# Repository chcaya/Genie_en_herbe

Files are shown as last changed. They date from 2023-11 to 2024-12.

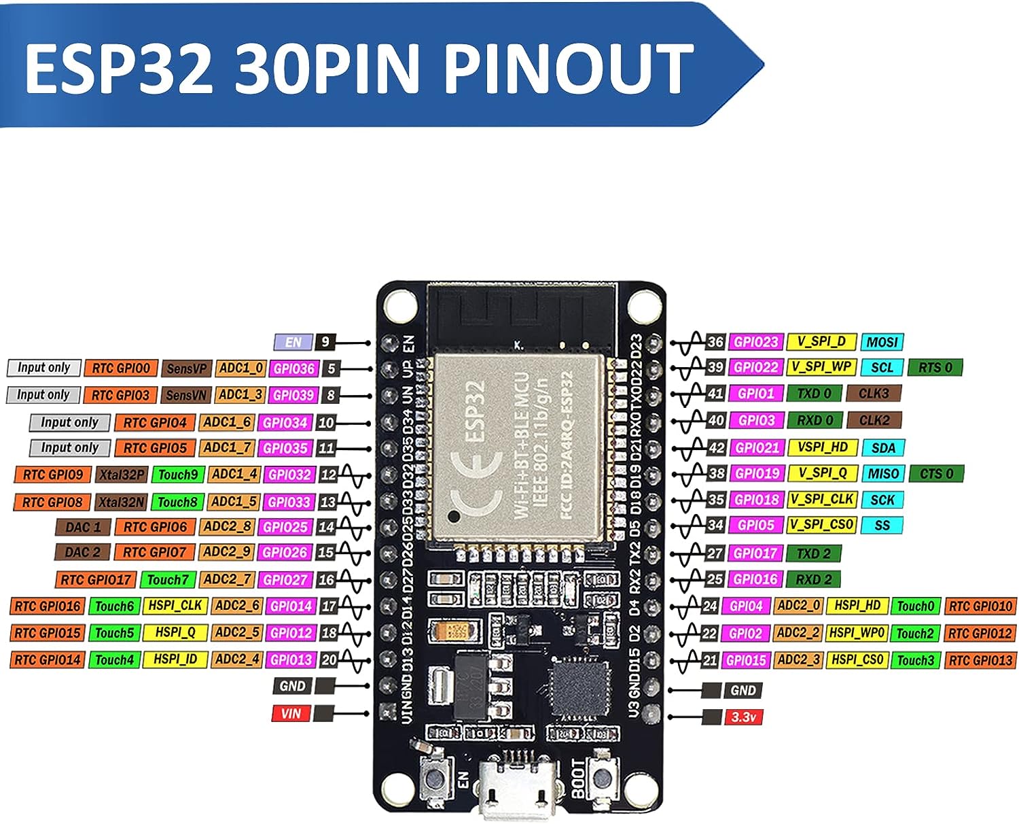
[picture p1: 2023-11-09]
MCU/DEV/ESP32/ESP32_PINOUT.jpg

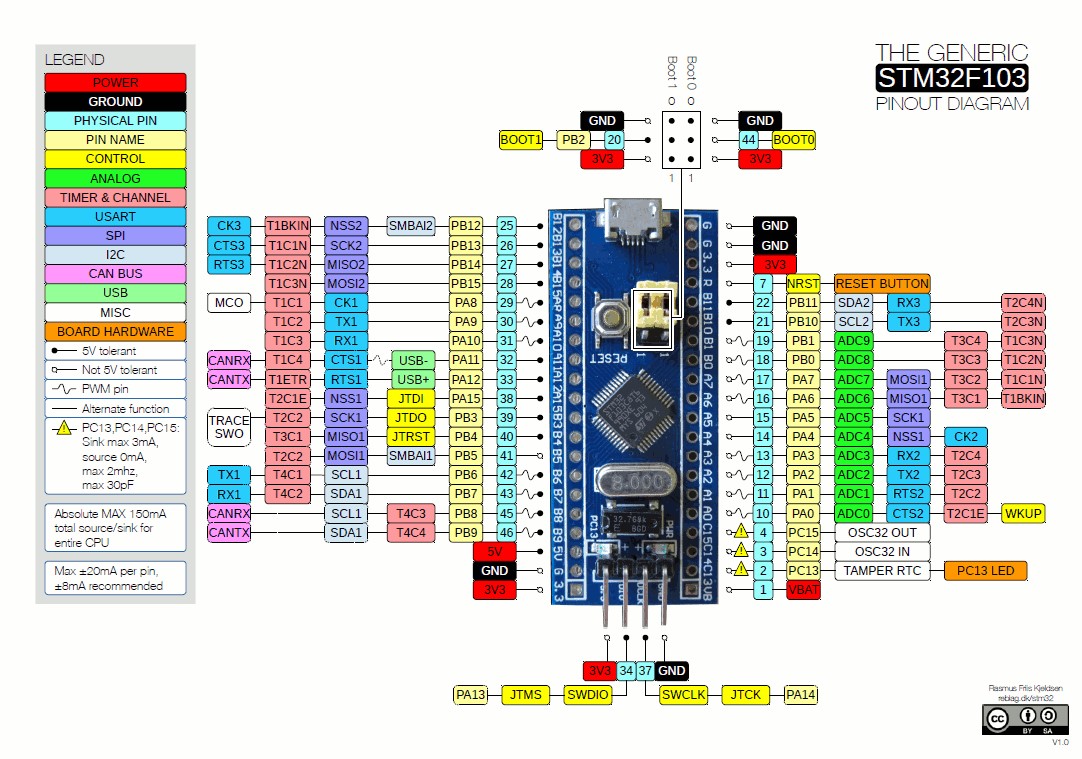
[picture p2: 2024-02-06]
MCU/DEV/STM32/STM32F103C8T6-Blue-Pill-Pin-Layout.jpg

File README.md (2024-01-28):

# Genie_en_herbe
Hardware, Firmware et Software pour la fabrication d'un jeu de génie en herbe

## Imprimer les fichiers STL dans le dossier /CAD/STL<br />
2x Handle_V4_Body_P1<br />
2x Handle_V4_Body_P2<br />
2x Handle_V4_Body_P3<br />
2x Handle_V4_Body_P4<br />
8x Handle_V4_Cover<br />
1x ESP32_CASE_V4_BASE<br />
1x ESP32_CASE_V4_COVER<br />

## Assemblage électrique
1- Connecter les grounds du ESP32 à 2 connecteurs Wago 5 pos<br />
2- Utiliser les connecteurs Wago 5 pos pour grounder tous les boutons (Fil noir)<br />
3- Connecter le fil rouge des boutons aux pins D15, D4, D16, D17 pour l'équipe 1<br />
4- Connecter le fil rouge des boutons aux pins D13, D14, D27, D26 pour l'équipe 2<br />
5- Passer les fils rouge et noir dans le trou de la poignée avant de souder les boutons sur ceux-ci<br />
6- Souder les fils rouge et noir sur les boutons<br />

## Assemblage mécanique
1- Utiliser 2x vis M3x16mm et 2x écrous pour assembler une poignée<br />
*Attention de faire sortir les fils par le trou central prévu à cet effet avant de visser solidement l'assemblage<br />
2- Utiliser 4x vis M3x16mm et 4x inserts pour assembler le boitier de jeu<br />
*Attention de faire sortir les fils par les 8 trous sur les côtés du boitier avant de visser solidement l'assemblage<br />

## Script code embarqué
1- Connecter l'ESP32 à l'ordinateur à l'aide du fil micro-USB (Valider la reconnaissance par l'ordinateur via le gestionnaire de périphériques)<br />
*Si celui-ci n'est pas reconnu, télécharger les drivers à partir de "/MCU/DEV/CP210x_Windows_Drivers_with_Serial_Enumeration/CP210xVCPInstaller_x86.exe"<br />
2- Lancer le script "MCU/UploadScript.exe" pour télécharger le code sur l'ESP32<br />
3- Attendre que tous les fichiers (bootloader.bin, partitions.bin et firmware.bin) soient correctement téléchargés avant d'interrompre le processus<br />

## Application GUI
1- Lancer l'application "/GUI/GEH_GUI.exe" lorsque l'ESP32 est connecté à l'ordinateur<br />
2- Sélectionner les équipes à l'aide des menus déroulants<br />
3- Lorsqu'un joueur appuie sur son bouton, le GUI indique le numéro et l'équipe du joueur<br />
4- Pour passer au prochain tour, il est possible d'appuyer sur le bouton "Reset" avec la souris ou simplement sur "Enter" avec le clavier

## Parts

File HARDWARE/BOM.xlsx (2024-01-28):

Qté d'unités | 1
Composant | Coût | Qté/unité | Qté lot | Coût/unité | Qté Amazon | Coût total | Lien
Boutons poussoirs* | 13.99 $ | 8 | 24 | 4.66 $ | 1 | 13.99 $ | https://www.amazon.ca/-/fr/gp/product/B07YCC4GTD/ref=ox_sc_act_title_8?smid=A86AD06S3OMVQ&psc=1
STM32* | 13.99 $ | 1 | 2 | 7.00 $ | 1 | 13.99 $ | https://www.amazon.ca/-/fr/gp/product/B0CKSYSSCZ/ref=ewc_pr_img_7?smid=A1ZMZWM9Z42FJB&psc=1
ESP32* | 22.16 $ | 0 | 2 | 0.00 $ | 0 | 0.00 $ | https://www.amazon.ca/-/fr/gp/product/B0BD4DVHZ9/ref=ox_sc_act_title_1?smid=A2K4DGCC72N9AG&psc=1
Fils micro USB 2m | 10.70 $ | 1 | 3 | 3.57 $ | 1 | 10.70 $ | https://www.amazon.ca/-/fr/gp/product/B08J3QCR8X/ref=ox_sc_act_title_6?smid=A2Y8CZ3LRW00G4&psc=1
Fils boutons (m) | 12.99 $ | 16 | 20 | 10.39 $ | 1 | 12.99 $ | https://www.amazon.ca/-/fr/gp/product/B074386X3V/ref=ox_sc_act_title_5?smid=A3UENWQOYWIPH9&psc=1
PLA | 31.99 $ | 0.3 | 1 | 9.60 $ | 1 | 31.99 $ | https://www.amazon.ca/-/fr/gp/product/B099KS2PDW/ref=ox_sc_act_title_1?smid=A3MZ696ES2UN1L&psc=1
Inserts | 10.59 $ | 4 | 100 | 0.42 $ | 1 | 10.59 $ | https://www.amazon.ca/-/fr/gp/product/B0BTYF2MMD/ref=ox_sc_act_title_4?smid=AKD305N0T0Z49&psc=1
Vis M3x16mm | 12.99 $ | 20 | 100 | 2.60 $ | 1 | 12.99 $ | https://www.amazon.ca/-/fr/t%C3%AAte-cylindrique-alliage-dacier-qualit%C3%A9/dp/B0BW891786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
Écrous M3 | 14.18 $ | 16 | 100 | 2.27 $ | 1 | 14.18 $ | https://www.amazon.ca/-/fr/%C3%A9crous-hexagonaux-auto-bloquants-inoxydable-ins%C3%A9r%C3%A9s/dp/B075ZZW7VL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
Borniers Wago 5 pos | 16.62 $ | 2 | 10 | 3.32 $ | 1 | 16.62 $ | https://www.amazon.ca/-/fr/gp/product/B06XH47DC2/ref=ewc_pr_img_8?smid=A3GIOIXY0M9FL0&psc=1
Connecteurs Dupont | 18.92 $ | 2 | 20 | 1.89 $ | 1 | 18.92 $ | https://www.amazon.ca/-/fr/gp/product/B07CTHCG5T/ref=ox_sc_act_title_2?smid=A3KY66I36TSYAT&psc=1
 |  |  |  | 45.72 $ |  | 156.96 $
*Même modèles nécessaires

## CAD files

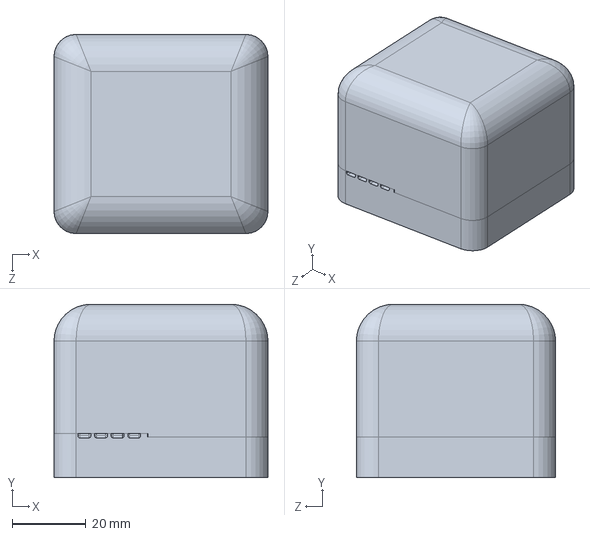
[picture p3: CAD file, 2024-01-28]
CAD/ESP32_CASE_V4.SLDPRT
58.0 x 47.0 x 54.0 mm

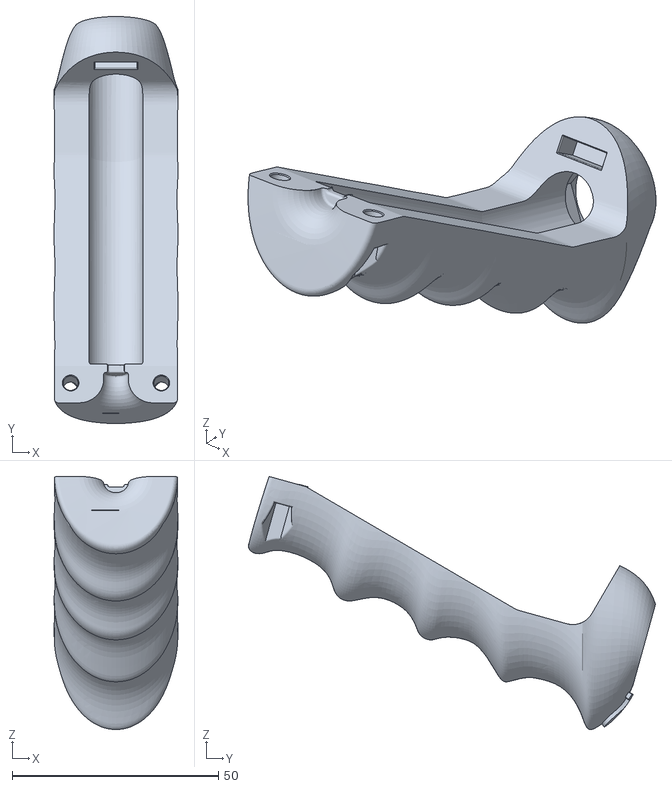
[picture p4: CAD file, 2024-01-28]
CAD/STL/Handle_V4_Body_P2.STL
30.0 x 98.6 x 61.4

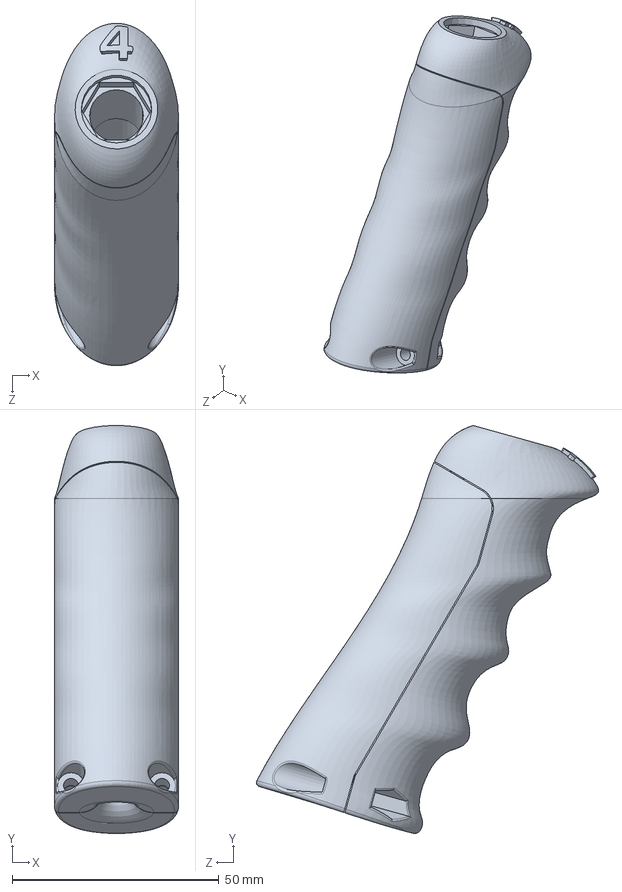
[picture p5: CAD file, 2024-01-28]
CAD/Handle_V4.SLDPRT
30.0 x 98.6 x 82.8 mm

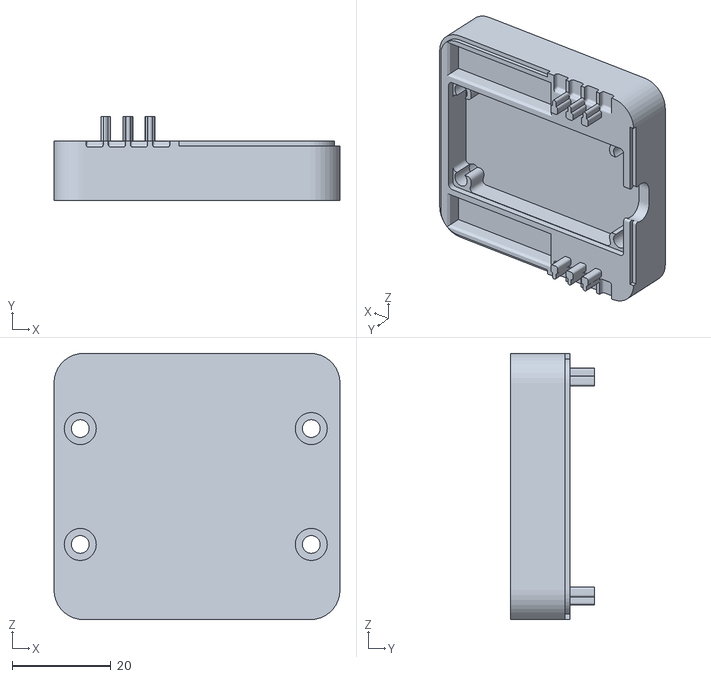
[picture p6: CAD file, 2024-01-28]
CAD/STL/ESP32_CASE_V4_BASE.STL
58.0 x 17.0 x 54.0

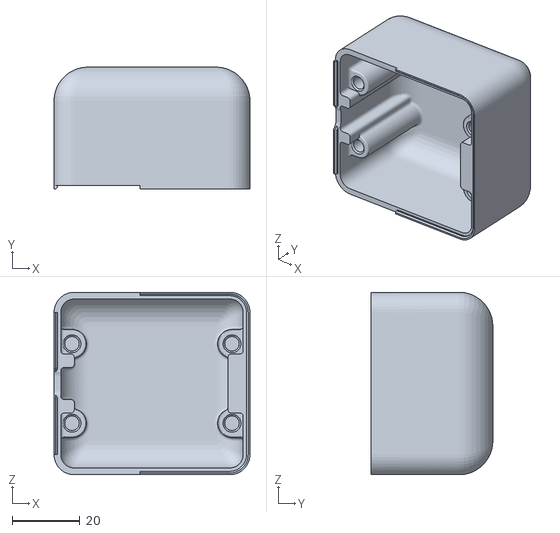
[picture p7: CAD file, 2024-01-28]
CAD/STL/ESP32_CASE_V4_COVER.STL
58.0 x 36.0 x 54.0

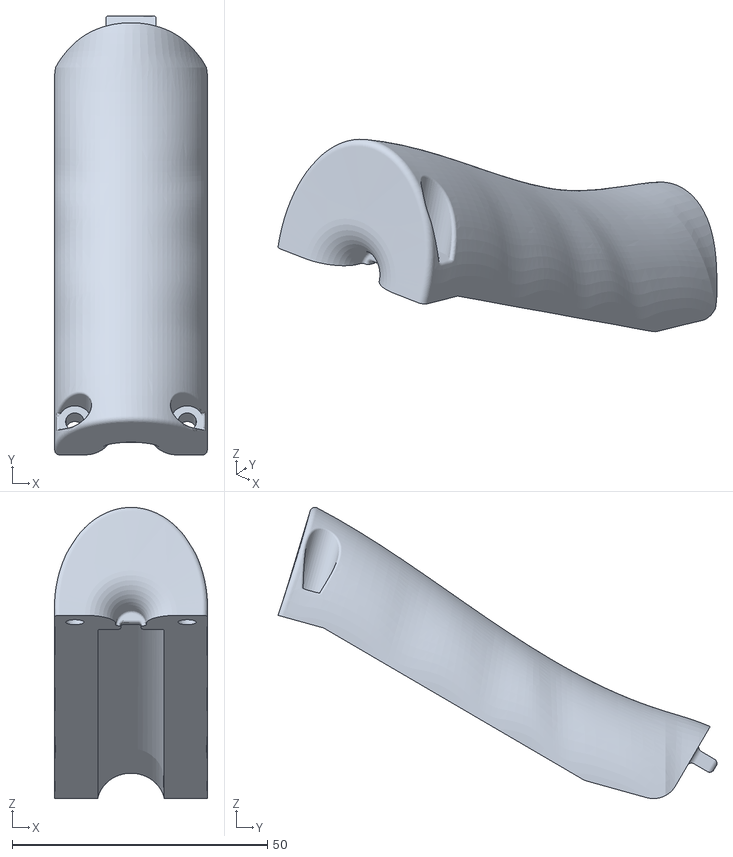
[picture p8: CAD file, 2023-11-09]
CAD/STL/Handle_V4_Cover.STL
30.0 x 86.0 x 57.0

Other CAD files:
CAD/STL/Handle_V4_Body_P3.STL
CAD/STL/Handle_V4_Body_P1.STL
CAD/STL/Handle_V4_Body_P4.STL
CAD/STL/Handle_V4_Body.STL

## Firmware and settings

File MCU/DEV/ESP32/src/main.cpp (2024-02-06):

#include <Arduino.h>

#define N_PLAYERS 8

#define PIN_T1P1 15
#define PIN_T1P2 4
#define PIN_T1P3 16
#define PIN_T1P4 17

#define PIN_T2P1 13
#define PIN_T2P2 14
#define PIN_T2P3 27
#define PIN_T2P4 26

uint8_t PIN_PLAYERS[N_PLAYERS] = {PIN_T1P1, PIN_T1P2, PIN_T1P3, PIN_T1P4,
                                  PIN_T2P1, PIN_T2P2, PIN_T2P3, PIN_T2P4};

uint8_t inputs = 0;
volatile bool isButtonPressed = false;
volatile bool hasPrinted = false;

void ResetInputs()
{
  inputs = 0;
  hasPrinted = false;
  isButtonPressed = false;
}

inline void ISRCore(const uint8_t playerID)
{
  if(!isButtonPressed)
  {
    isButtonPressed = true;
    inputs |= (1 << playerID);
  }
}

void IRAM_ATTR ISRP1()
{
  ISRCore(0);
}

void IRAM_ATTR ISRP2()
{
  ISRCore(1);
}

void IRAM_ATTR ISRP3()
{
  ISRCore(2);
}

void IRAM_ATTR ISRP4()
{
  ISRCore(3);
}

void IRAM_ATTR ISRP5()
{
  ISRCore(4);
}

void IRAM_ATTR ISRP6()
{
  ISRCore(5);
}

void IRAM_ATTR ISRP7()
{
  ISRCore(6);
}

void IRAM_ATTR ISRP8()
{
  ISRCore(7);
}


void setup()
{
  Serial.begin(115200);

  for(uint8_t i = 0; i < N_PLAYERS; ++i)
  {
    pinMode(PIN_PLAYERS[i], INPUT_PULLUP);
  }

  attachInterrupt(PIN_PLAYERS[0], ISRP1, FALLING);
  attachInterrupt(PIN_PLAYERS[1], ISRP2, FALLING);
  attachInterrupt(PIN_PLAYERS[2], ISRP3, FALLING);
  attachInterrupt(PIN_PLAYERS[3], ISRP4, FALLING);
  attachInterrupt(PIN_PLAYERS[4], ISRP5, FALLING);
  attachInterrupt(PIN_PLAYERS[5], ISRP6, FALLING);
  attachInterrupt(PIN_PLAYERS[6], ISRP7, FALLING);
  attachInterrupt(PIN_PLAYERS[7], ISRP8, FALLING);

  ResetInputs();
}

void loop()
{
  if (Serial.available() > 0)
  {
    char command = Serial.read();
    if (command == 'R')
    {
      // Reset scores requested, perform the reset
      ResetInputs();
    }
  }

  if(isButtonPressed && !hasPrinted)
  {
    Serial.println(inputs);
    hasPrinted = true;
  }
}

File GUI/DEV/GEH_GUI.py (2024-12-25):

import customtkinter as ctk
import serial
import serial.tools.list_ports
import pygame

def set_player_id(team_index, player_id):
    team_player_id[team_index] = player_id
    update_player_id_display()

def reset():
    global team_player_id
    team_player_id = ["", ""]
    # Send a reset command to the Arduino
    ser.write(b"R\n")  # b"RESET\n" converts the string to bytes
    #print("Reset")
    update_player_id_display()

def bind_reset_to_enter(event):
    reset()

def update_player_id_display():
    for i in range(2):
        display_square = display_squares[i]
        display_square.delete("all")
        size = 30
        padding = 5
        score = team_player_id[i]

        # Add the score as text inside the canvas
        text_x = display_square.winfo_reqwidth() / 2
        text_y = display_square.winfo_reqheight() / 2
        display_square.create_text(text_x, text_y, text=str(score), font=("Roboto", 24))

def create_column(container, team_index):
    column_frame = ctk.CTkFrame(container)
    column_frame.grid(row=0, column=team_index)

    Combobox = ctk.CTkComboBox(master=column_frame,
                                values=team_labels,
                                command=combobox_cb,
                                font=("Roboto", 12))
    Combobox.set("Select team")
    Combobox.grid(row=0, column=0)

    square_frame = ctk.CTkFrame(column_frame)
    square_frame.grid(row=1, column=0, padx=5, pady=5)

    square = ctk.CTkCanvas(square_frame, width=200, height=30, bg="grey")
    square.pack(ipadx=5, ipady=5)
    display_squares.append(square)

def combobox_cb(choice):
    print(choice)

def detect_mcu_com_port():
    mcu_com_port = None

    # Get a list of available serial ports
    available_ports = list(serial.tools.list_ports.comports())

    for port in available_ports:
        if "CP210x" in port.description:
            mcu_com_port = port.device
            break
        
        if "Maple" in port.description:
            mcu_com_port = port.device
            break

        if "Serial" in port.description:
            mcu_com_port = port.device
            break

    return mcu_com_port

def read_serial_data():
    try:
        serial_data = ser.readline().decode()

        if len(serial_data) > 0:
            print(str(serial_data))
            input_data = int(serial_data)
            print(str(input_data))
            pressed_players = []

            for i in range(8):  # Assuming 8 bits
                if input_data & (1 << i):
                    pressed_players.append(i)

            str_team0 = ""
            str_team1 = ""

            if len(pressed_players) > 1:
                str_team0 += "D "
                str_team1 += "D "

            for i in pressed_players:
                if 0 <= i <= 3:
                    player_id = i+1
                    str_team0 += str(player_id) + " "
                
                elif 4 <= i <= 7:
                    player_id = i-3
                    str_team1 += str(player_id) + " "
            
            pygame.mixer.music.play()
            set_player_id(0, str_team0)
            set_player_id(1, str_team1)

    except ValueError:
        pass  # Handle invalid data (non-integer values)

    # Schedule the read_serial_data() function to be called again after 100ms
    root.after(100, read_serial_data)



team_player_id = [0, 0]
display_squares = []
team_labels =   ["ULaval",
                "Poly",
                "MgCil",
                "Conco",
                "Sherby",
                "UQTR",
                "ETS",
                "UQAT",
                "UQOttawa",
                "UQAC",
                "RiMoncton",
                "Drummond"]

ctk.set_appearance_mode("dark")
ctk.set_default_color_theme("dark-blue")

root = ctk.CTk()
root.title("GEH")

pygame.mixer.init()
pygame.mixer.music.load("buzz_sound.wav")

container_frame = ctk.CTkFrame(root)
container_frame.grid(row=0, column=0, padx=10, pady=10)

# Create the columns inside the container frame and pass the reset_button
create_column(container_frame, 0)
create_column(container_frame, 1)
reset_button = ctk.CTkButton(root, text="Reset", command=reset)
reset_button.grid(row=2, column=0, columnspan=2, padx=10, pady=10)

root.bind("<Return>", bind_reset_to_enter)

mcu_com_port = detect_mcu_com_port()

if mcu_com_port is None:
    print("MCU not found.")
else:
    print("MCU detected on:", mcu_com_port)

# Open the serial port for communication with the MCU
ser = serial.Serial(mcu_com_port, 115200, timeout=1)

reset()

# Schedule the read_serial_data() function to be called initially and then every 100ms
root.after(0, read_serial_data)

root.mainloop()

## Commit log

2023-12-22 Fixed delay with newline char
    [main.cpp]
2024-01-28 MCU now uses interrupts
2024-01-28 Deleted prints in GUI
2024-01-28 Improved CAD design
    [ESP32_CASE_V3_BASE.STL, ESP32_CASE_V3_COVER.STL, ESP32_CASE_V4.SLDPRT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]
2024-01-28 Deleted CASE_V3
    [ESP32_CASE_V3.SLDPRT]
2024-01-28 Updated BOM
    [BOM.xlsx]
2024-02-06 Added STM32 option
2024-02-06 Updated GUI to detect STM32
2024-02-06 ESP32 file architecture mod
2024-12-25 Added Serial to detectable device
